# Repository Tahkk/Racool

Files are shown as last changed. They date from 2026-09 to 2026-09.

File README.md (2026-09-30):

# 🦝 Racool — Innoserv Awards Contest

<div align="center">
  Racool raccoon mascot
  
</div>

## About

This repository hosts the hardware design presented at the *Innoserv Awards Contest*, held in October 2025 in Taiwan.

**Racool** is a compact PCB that estimates how many people are present in a closed space without cameras and without identifying anyone. It combines a 60 GHz radar for presence/occupancy sensing with a CO₂ / temperature / humidity sensor, all driven by an ESP32 microcontroller with Wi‑Fi and Bluetooth LE connectivity.

## Use cases

Racool is designed for any enclosed space where occupancy and air quality matter:

- Public transport (buses, trains, metros)
- Hospital and clinic waiting rooms
- Restaurants and cafés
- Gyms and fitness clubs
- Offices, meeting rooms, classrooms

## Key features

- **Anonymous by design**: radar sensing captures no images, no sound and no personal data.
- **Air-quality awareness**: real CO₂, temperature and humidity measurements.
- **Wireless**: Wi‑Fi and BLE for data reporting.
- **Compact & simple**: single board, powered and programmed over USB‑C.

## Hardware

- **ESP32‑C3‑WROOM‑02** : Main MCU with Wi‑Fi and BLE; runs the firmware and processes sensor data 
- **BGT60TR13C** (Infineon) : 60 GHz FMCW radar sensor used for presence / occupancy detection 
- **SCD41** (Sensirion) : Photoacoustic CO₂ sensor with integrated temperature and humidity sensing 
- **MP2232HGTL** : Power management 
- **USB‑C connector** : Programming and power supply 

## How it works

```
 ┌────────────┐  SPI   ┌──────────────┐        ┌────────────────┐
 │ BGT60TR13C │───────▶│              │  Wi‑Fi │  Cloud /       │
 │ (60 GHz)   │        │  ESP32‑C3    │───────▶│  dashboard     │
 └────────────┘        │              │  BLE   │  (optional)    │
 ┌────────────┐  I²C   │              │        └────────────────┘
 │   SCD41    │───────▶│              │
 │ CO₂/T/RH   │        └──────────────┘
 └────────────┘              ▲
                        USB‑C / power
```

1. The radar captures motion and micro-motion signatures in the room.
2. The MCU processes them to estimate occupancy.
3. The SCD41 provides CO₂, temperature and humidity readings.
4. Data is sent over Wi‑Fi/BLE to a dashboard or gateway.

## Layers and 3D view

<div align="center">
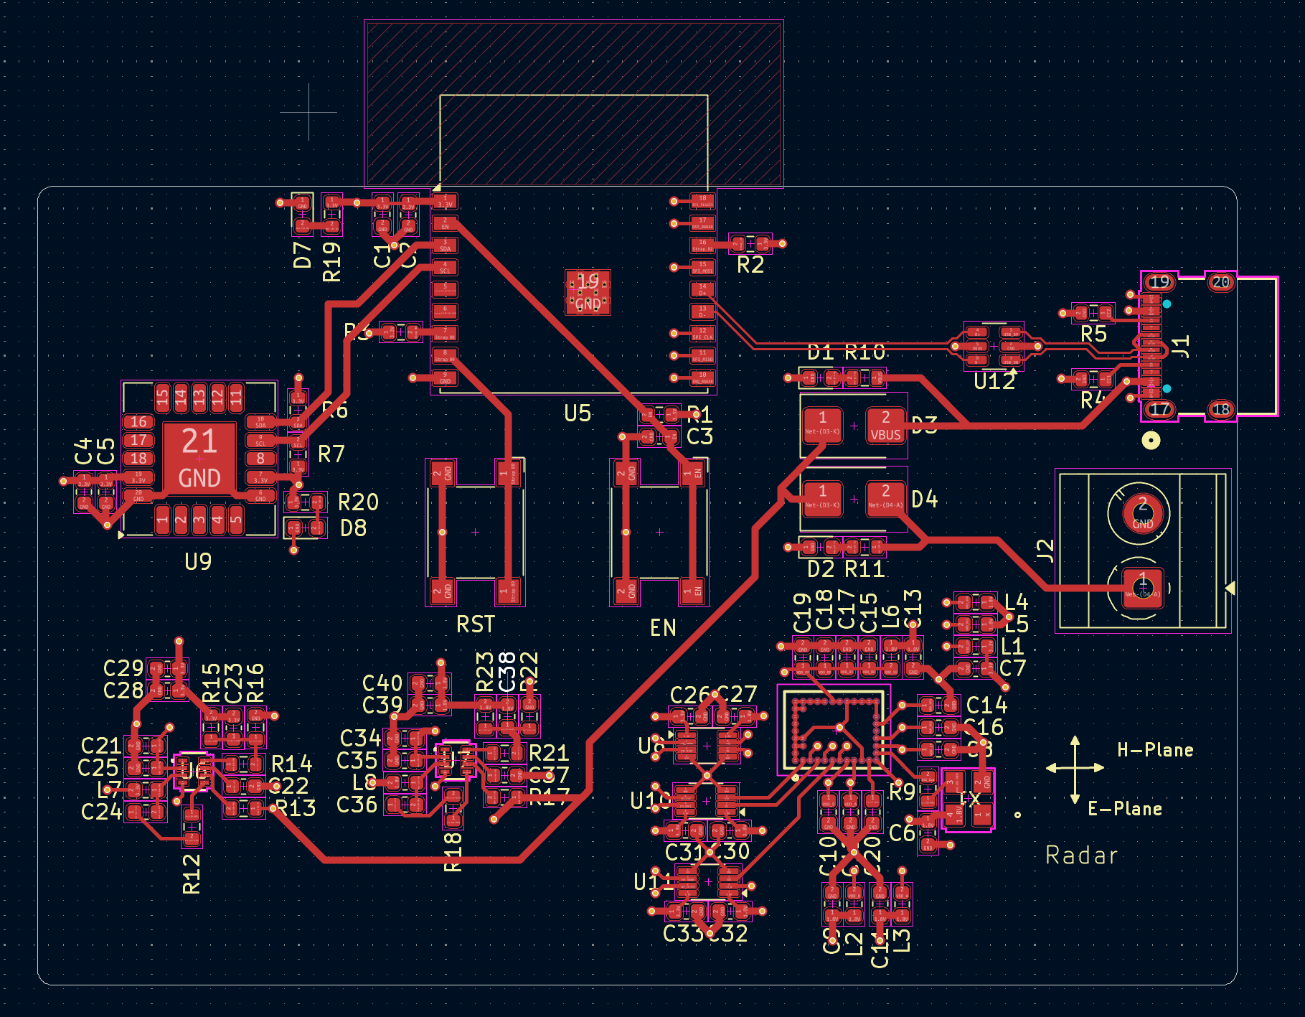
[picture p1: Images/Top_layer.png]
<br>
Top layer<br>

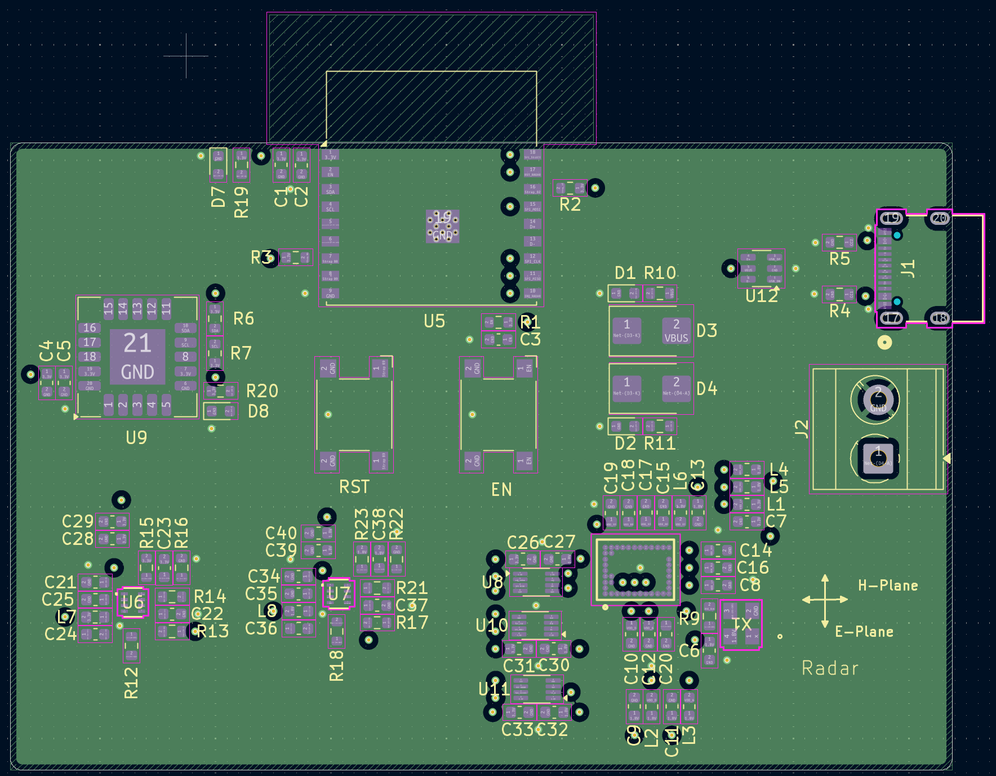
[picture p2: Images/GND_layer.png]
<br>
  Ground layer<br>
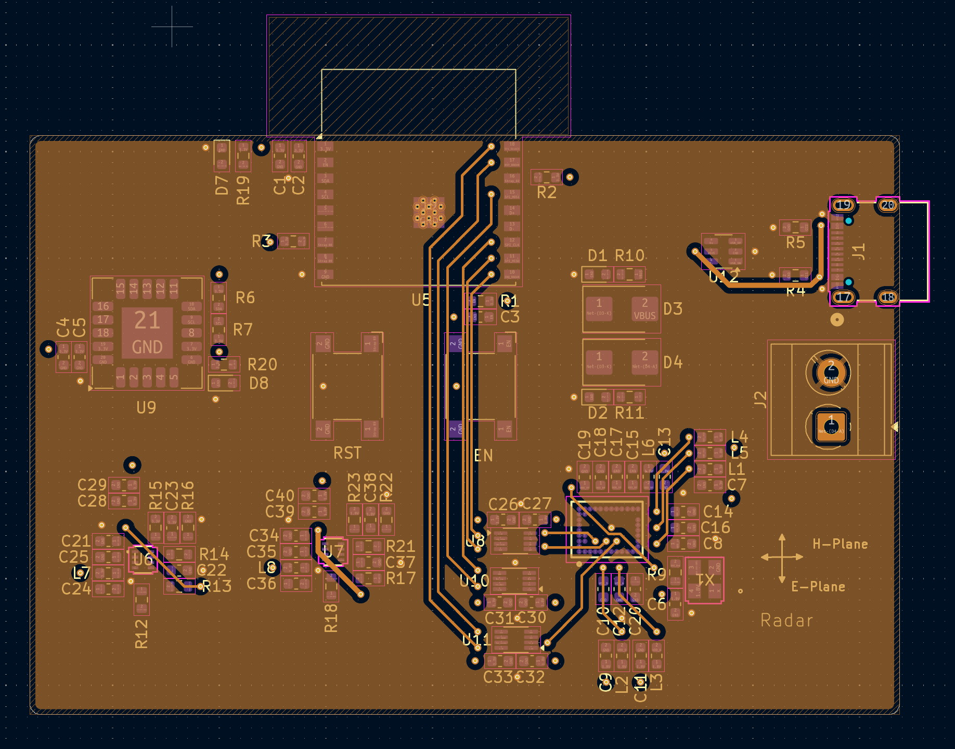
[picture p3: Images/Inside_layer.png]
<br>
  Inside layer<br>
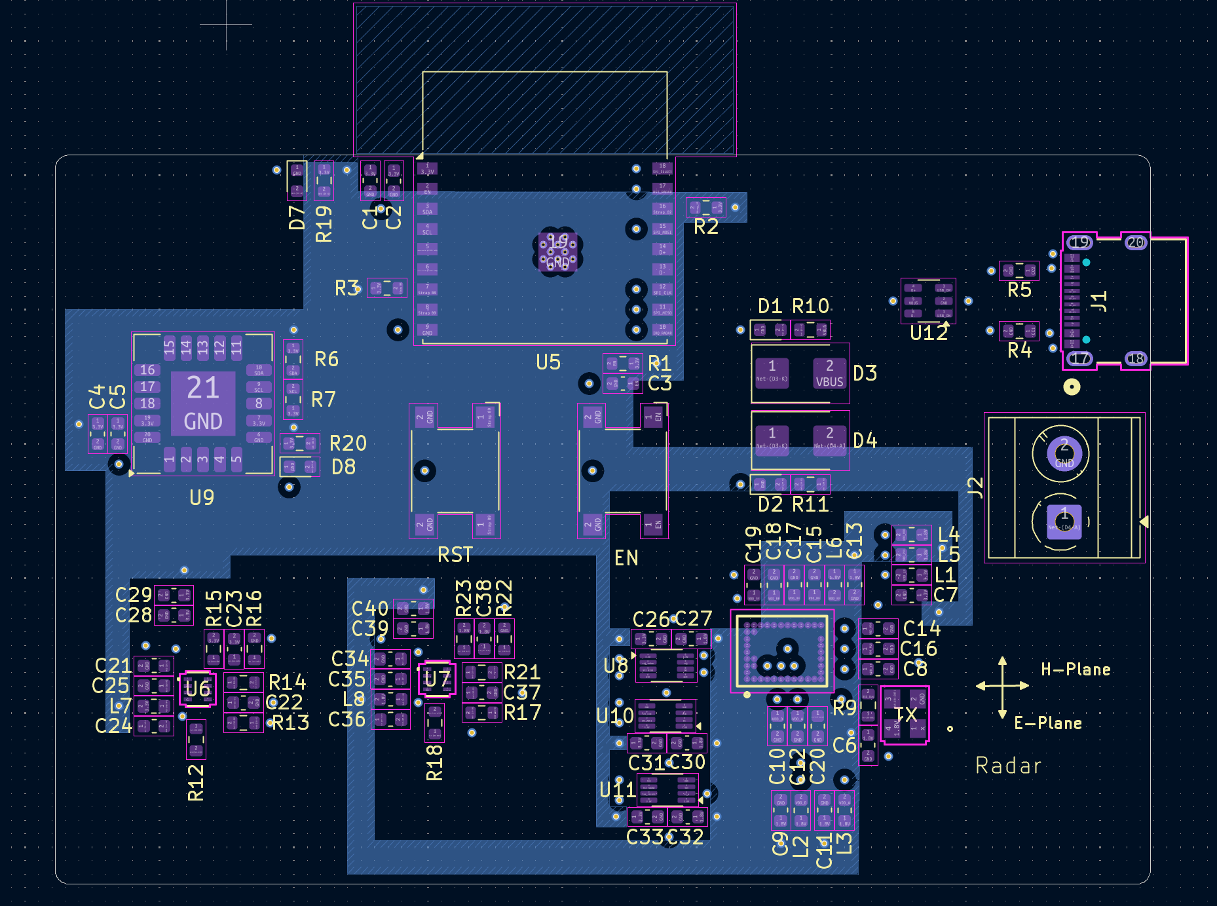
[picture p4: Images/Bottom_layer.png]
<br>
  Bottom layer<br>
</div>

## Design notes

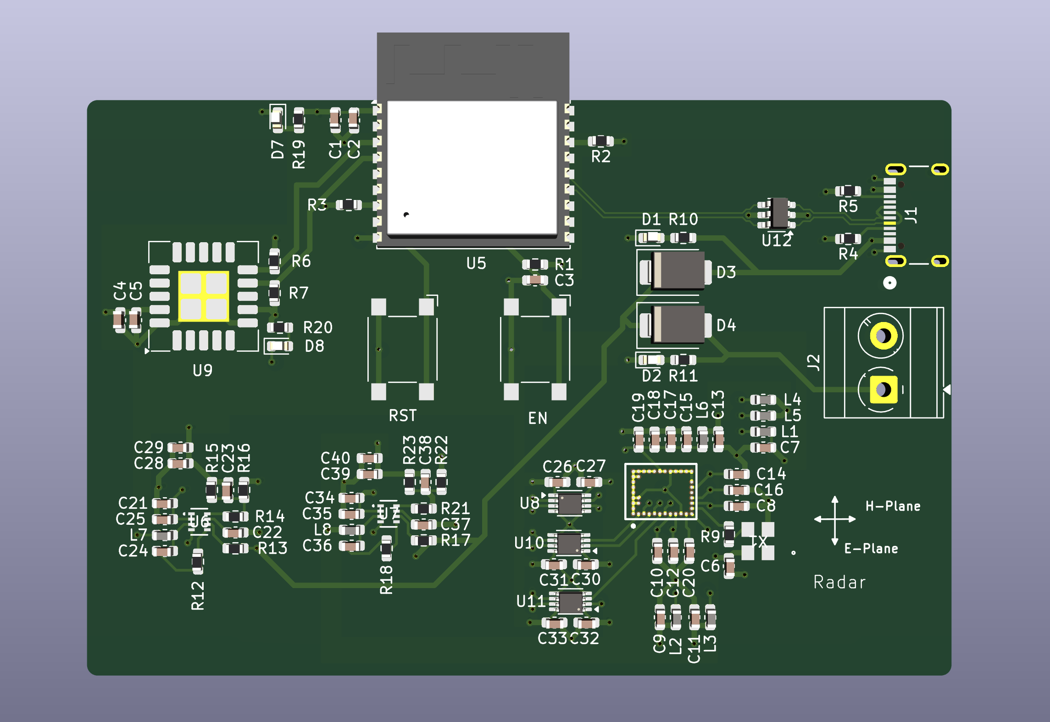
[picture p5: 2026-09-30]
Images/3D.png

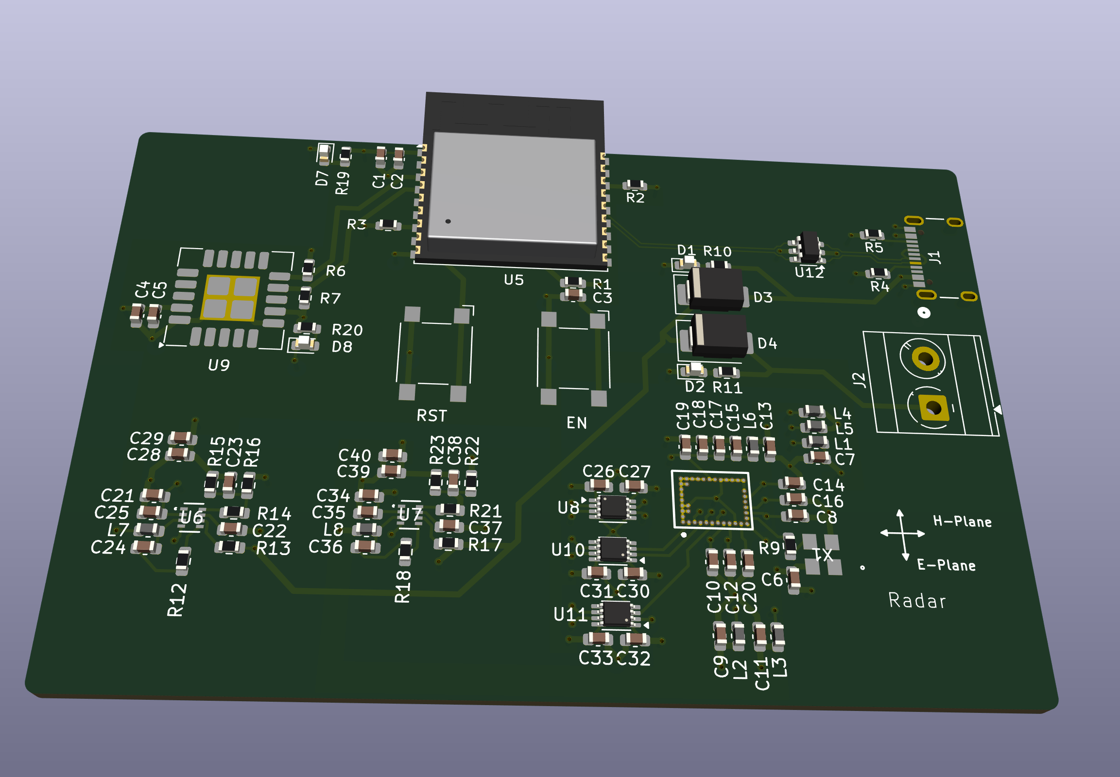
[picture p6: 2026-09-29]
Kicad_files/3D board.png

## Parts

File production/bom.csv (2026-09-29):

Designator | Footprint | Quantity | Value | LCSC Part #
C1, C12, C13, C15, C22, C37, C4, C7, C9 | 0603 | 9 | 10µF
C10, C14, C16, C17, C18, C19, C24, C3, C36, C8 | 0603 | 10 | 1µF
C11, C5 | 0603 | 2 | 100nF
C2, C25, C26, C27, C30, C31, C32, C33, C35 | 0603 | 9 | 0.1µF
C20 | 0603 | 1 | 470nF
C21, C28, C29, C34, C39, C40 | 0603 | 6 | 22µF
C23, C38 | 0603 | 2 | 10pF
C6 | 0603 | 1 | 0.01µF
D1 | 0603 | 1 | B_LED
D2, D7, D8 | 0603 | 3 | R_LED
D3, D4 | D_SMB | 2 | MBRS130LT3
EN, RST | SW_SPST_Omron_B3FS-100xP | 2 | SW_Omron_B3FS
J1 | CONN12_B-7004_GSW | 1 | GT-USB-7004
J2 | TerminalBlock_MetzConnect_Type073_RT02602HBLU_1x02_P5.08mm_Horizontal | 1 | 5V
L1, L2, L3, L4, L5, L6 | 0603 | 6 | L
L7 | 0603 | 1 | 0.47µH
L8 | 0603 | 1 | 0.68µH
R1, R2, R3 | 0603 | 3 | 10k
R10 | 0603 | 1 | 220
R11 | 0603 | 1 | 300
R12, R18 | 0603 | 2 | 20
R13, R17 | 0603 | 2 | 120k
R14, R15, R23 | 0603 | 3 | 40.2k
R16 | 0603 | 1 | 13k
R19, R20 | 0603 | 2 | 1k
R21 | 0603 | 1 | 20k
R22 | 0603 | 1 | 32.4k
R4, R5 | 0603 | 2 | 5k1
R6, R7 | 0603 | 2 | 4.7k
R9 | 0603 | 1 | 150
U$1 | BGA40N50P9X12_500X650X90-V | 1 | BGT60TR13C
U10, U11, U8 | VSSOP-8_2.3x2mm_P0.5mm | 3 | SN74LVC2T45DCUR
U12 | SOT-23-6 | 1 | USBLC6-2SC6
U5 | ESP32-C3-WROOM-02 | 1 | ESP32-C3-WROOM-02
U6, U7 | SOT583_MP2332H_MNP | 2 | MP2332HGTL-Z
U9 | Sensirion_SCD4x-1EP_10.1x10.1mm_P1.25mm_EP4.8x4.8mm | 1 | SCD41-D-R2
X1 | SON4_SIT8008_3p2x2p5_SIT | 1 | TXC CORP 7X80000600

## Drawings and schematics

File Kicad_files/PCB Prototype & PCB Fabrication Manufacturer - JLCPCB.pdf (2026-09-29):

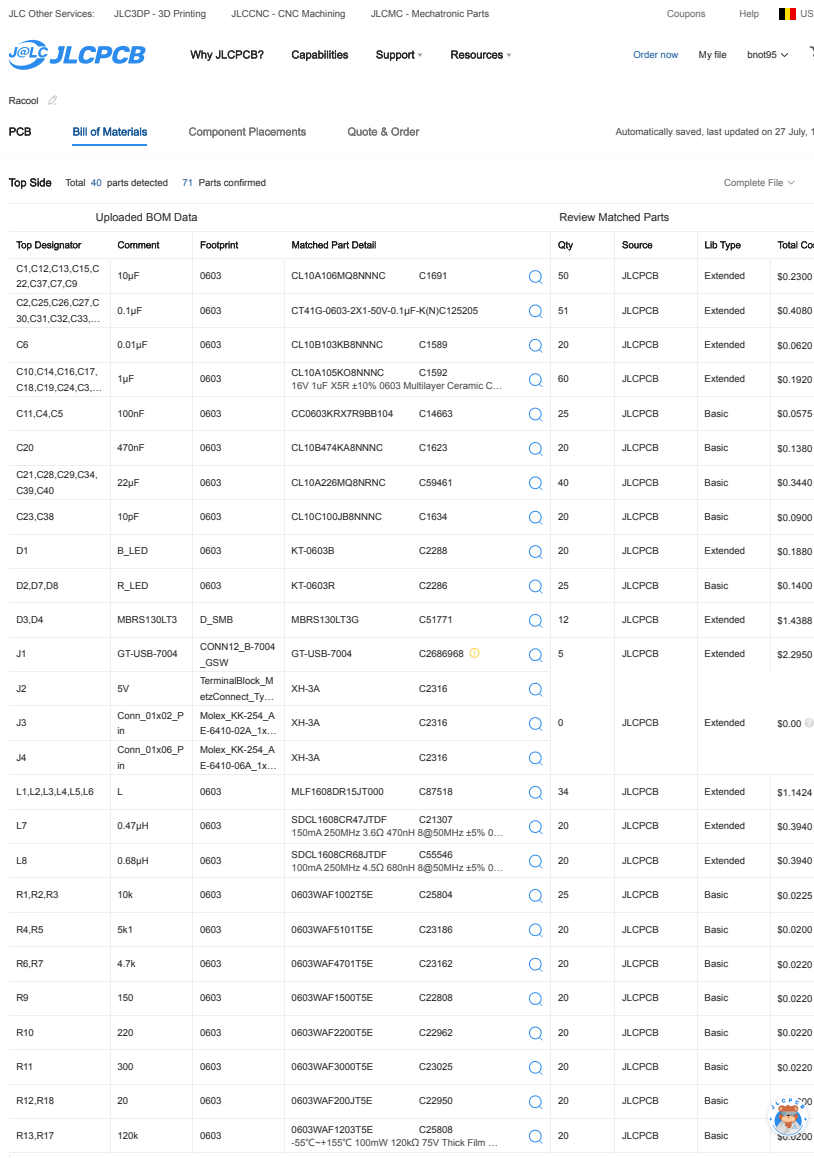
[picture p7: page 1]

Automatically saved, last updated on 27 July, 1

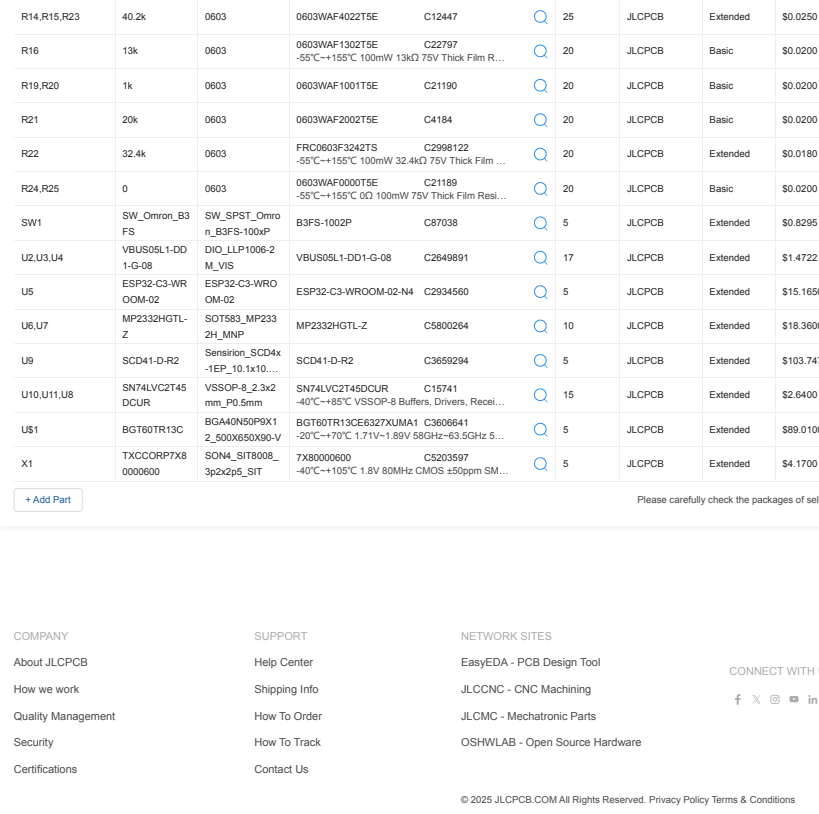
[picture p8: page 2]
COMPANY; About JLCPCB; Quality Management; Security; Certifications; SUPPORT; Help Center; Shipping Info; Contact Us; NETWORK SITES; CONNECT WITH U; + Add Part; Please carefully check the packages of sel; 0603WAF4022T5E; JLCPCB; Extended; 0603WAF1302T5E; -55℃~+155℃ 100mW 13kΩ 75V Thick Film R…; Basic; 0603WAF1001T5E; 0603WAF2002T5E; FRC0603F3242TS; -55℃~+155℃ 100mW 32.4kΩ 75V Thick Film …; 0603WAF0000T5E; SW_Omron_B3 FS; SW_SPST_Omro n_B3FS-100xP; VBUS05L1-DD 1-G-08; DIO_LLP1006-2 M_VIS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

-55℃~+155℃ 0Ω 100mW 75V Thick Film Resi…

-40℃~+85℃ VSSOP-8 Buffers, Drivers, Recei…

EasyEDA - PCB Design Tool (https://easyeda.com/)

How we work (https://jlcpcb.com/aboutUs/howWorks)

JLCCNC - CNC Machining (https://jlccnc.com/?source=jlcpcb-footer)

How To Order (https://jlcpcb.com/help/catalog/11-How-To-Order)

JLCMC - Mechatronic Parts (https://jlcmc.com/?href=jlc-footer&source=jlc)

How To Track (https://jlcpcb.com/help/article/How-to-Track-My-Order)

OSHWLAB - Open Source Hardware (https://oshwlab.com/?source=jlcpcb-footer)

© 2025 JLCPCB.COM All Rights Reserved. Privacy Policy (https://jlcpcb.com/help/article/Privacy-Policy) Terms & Conditions (https://jlcpcb.com/help/article/Terms-%26-Conditions)

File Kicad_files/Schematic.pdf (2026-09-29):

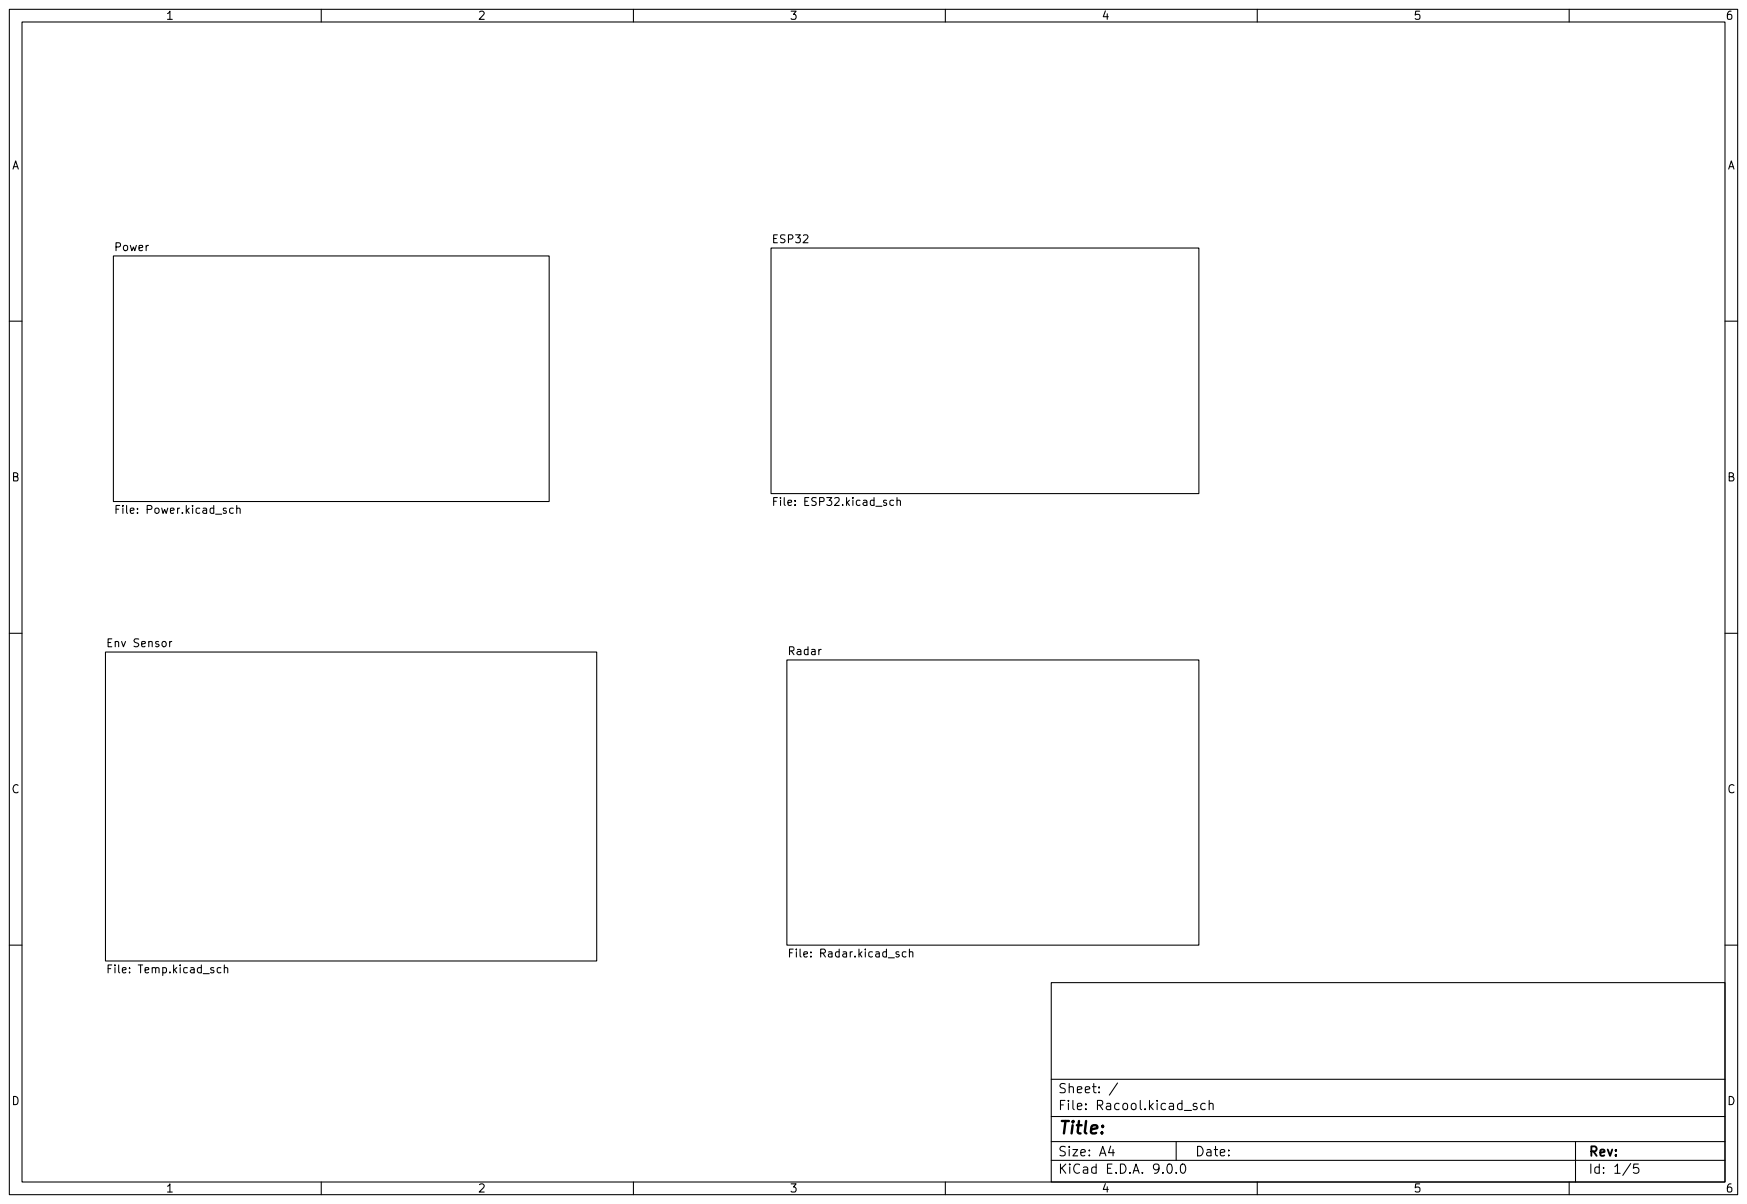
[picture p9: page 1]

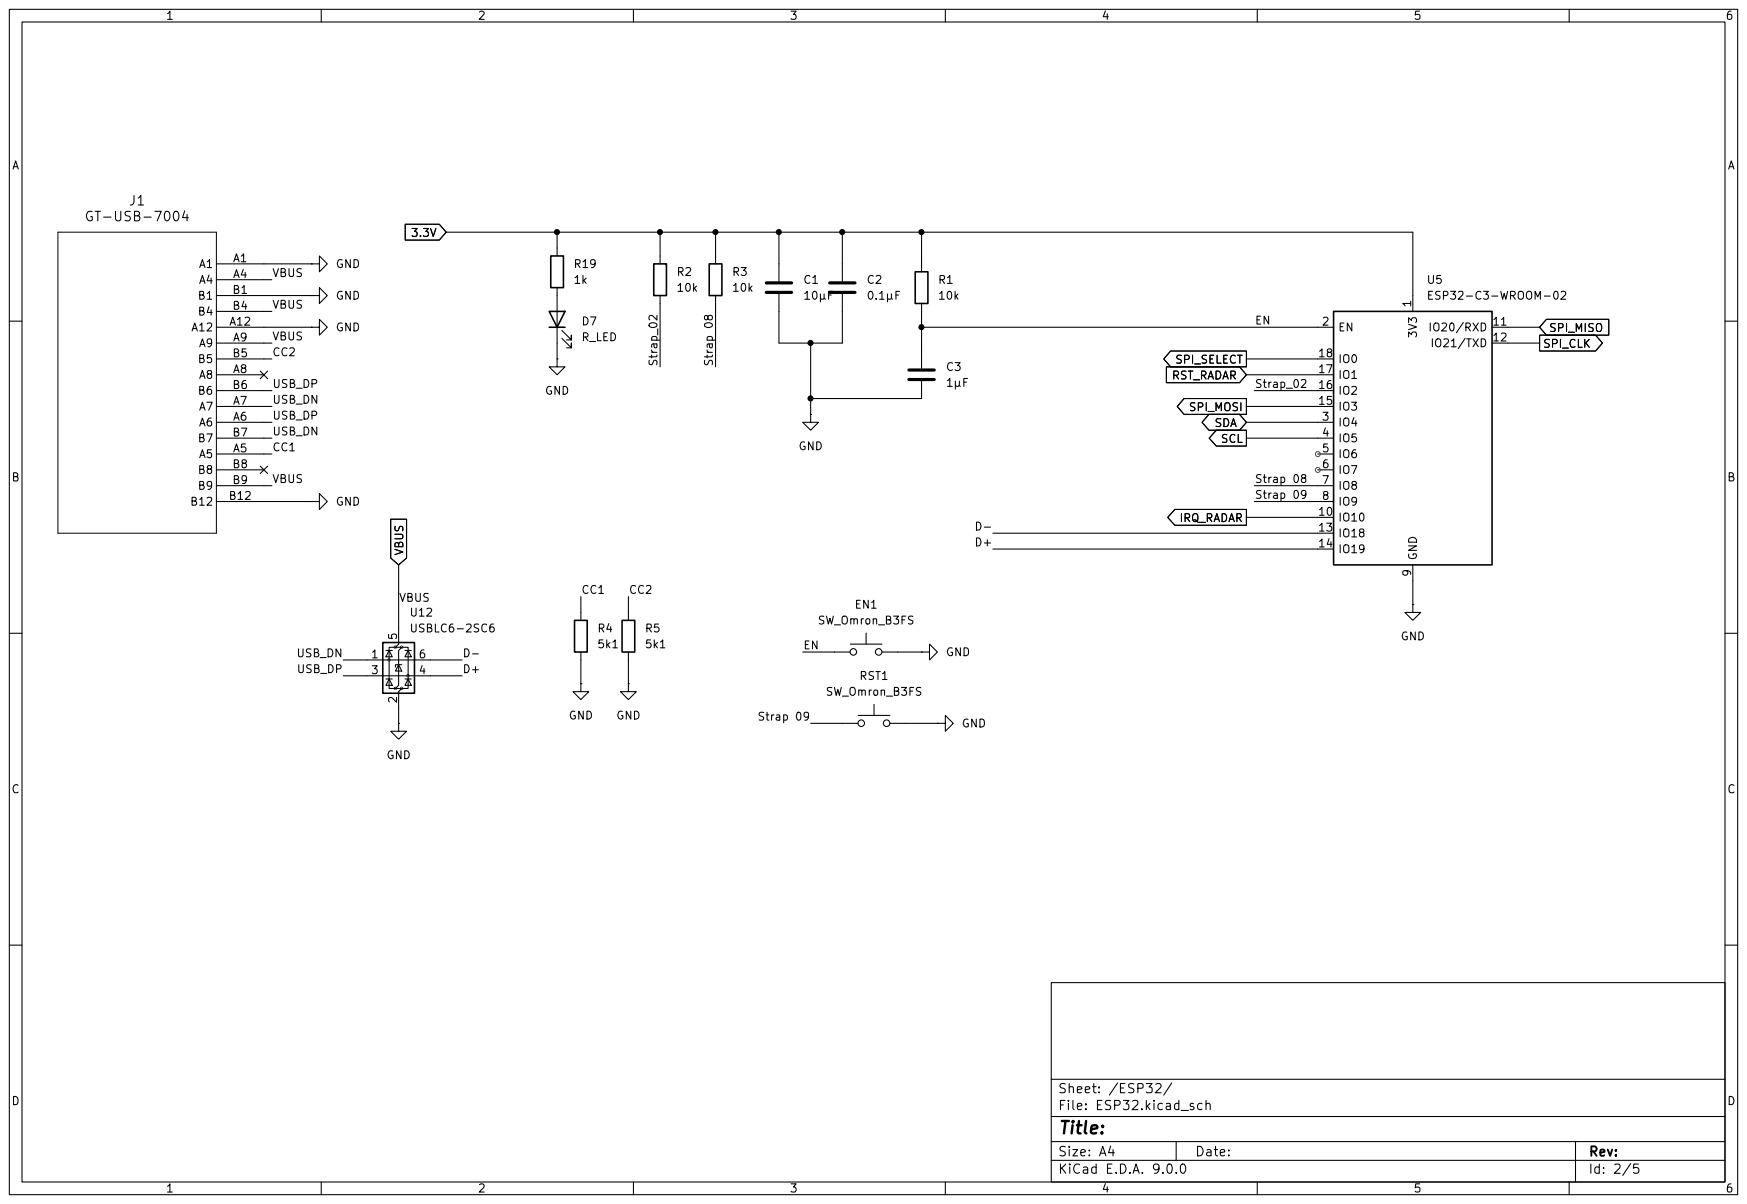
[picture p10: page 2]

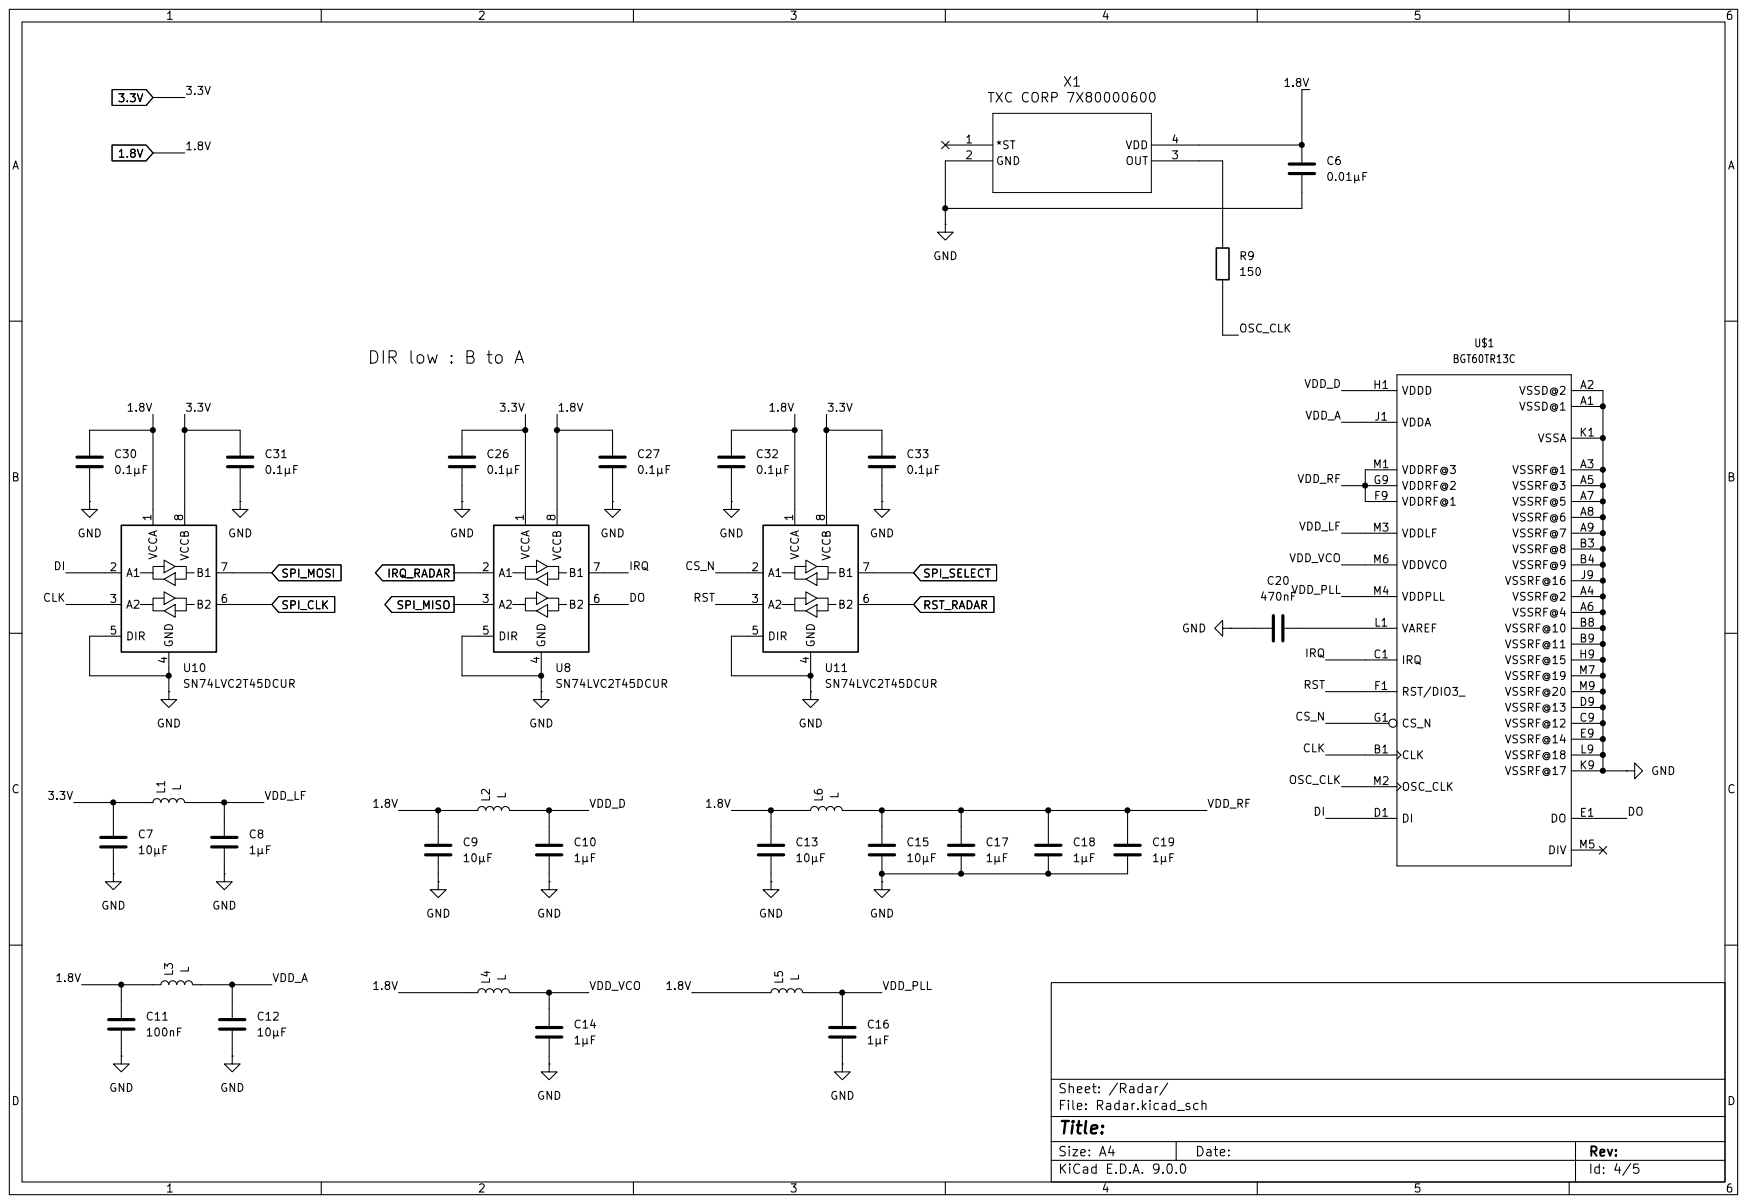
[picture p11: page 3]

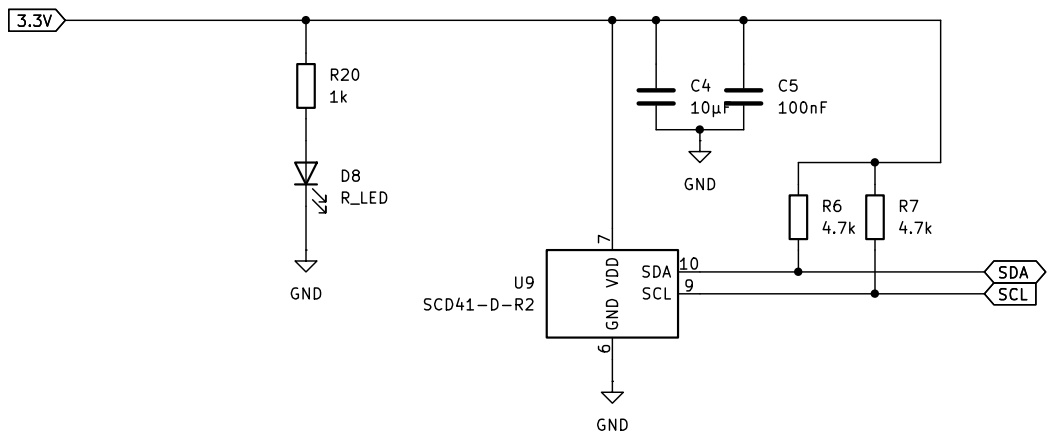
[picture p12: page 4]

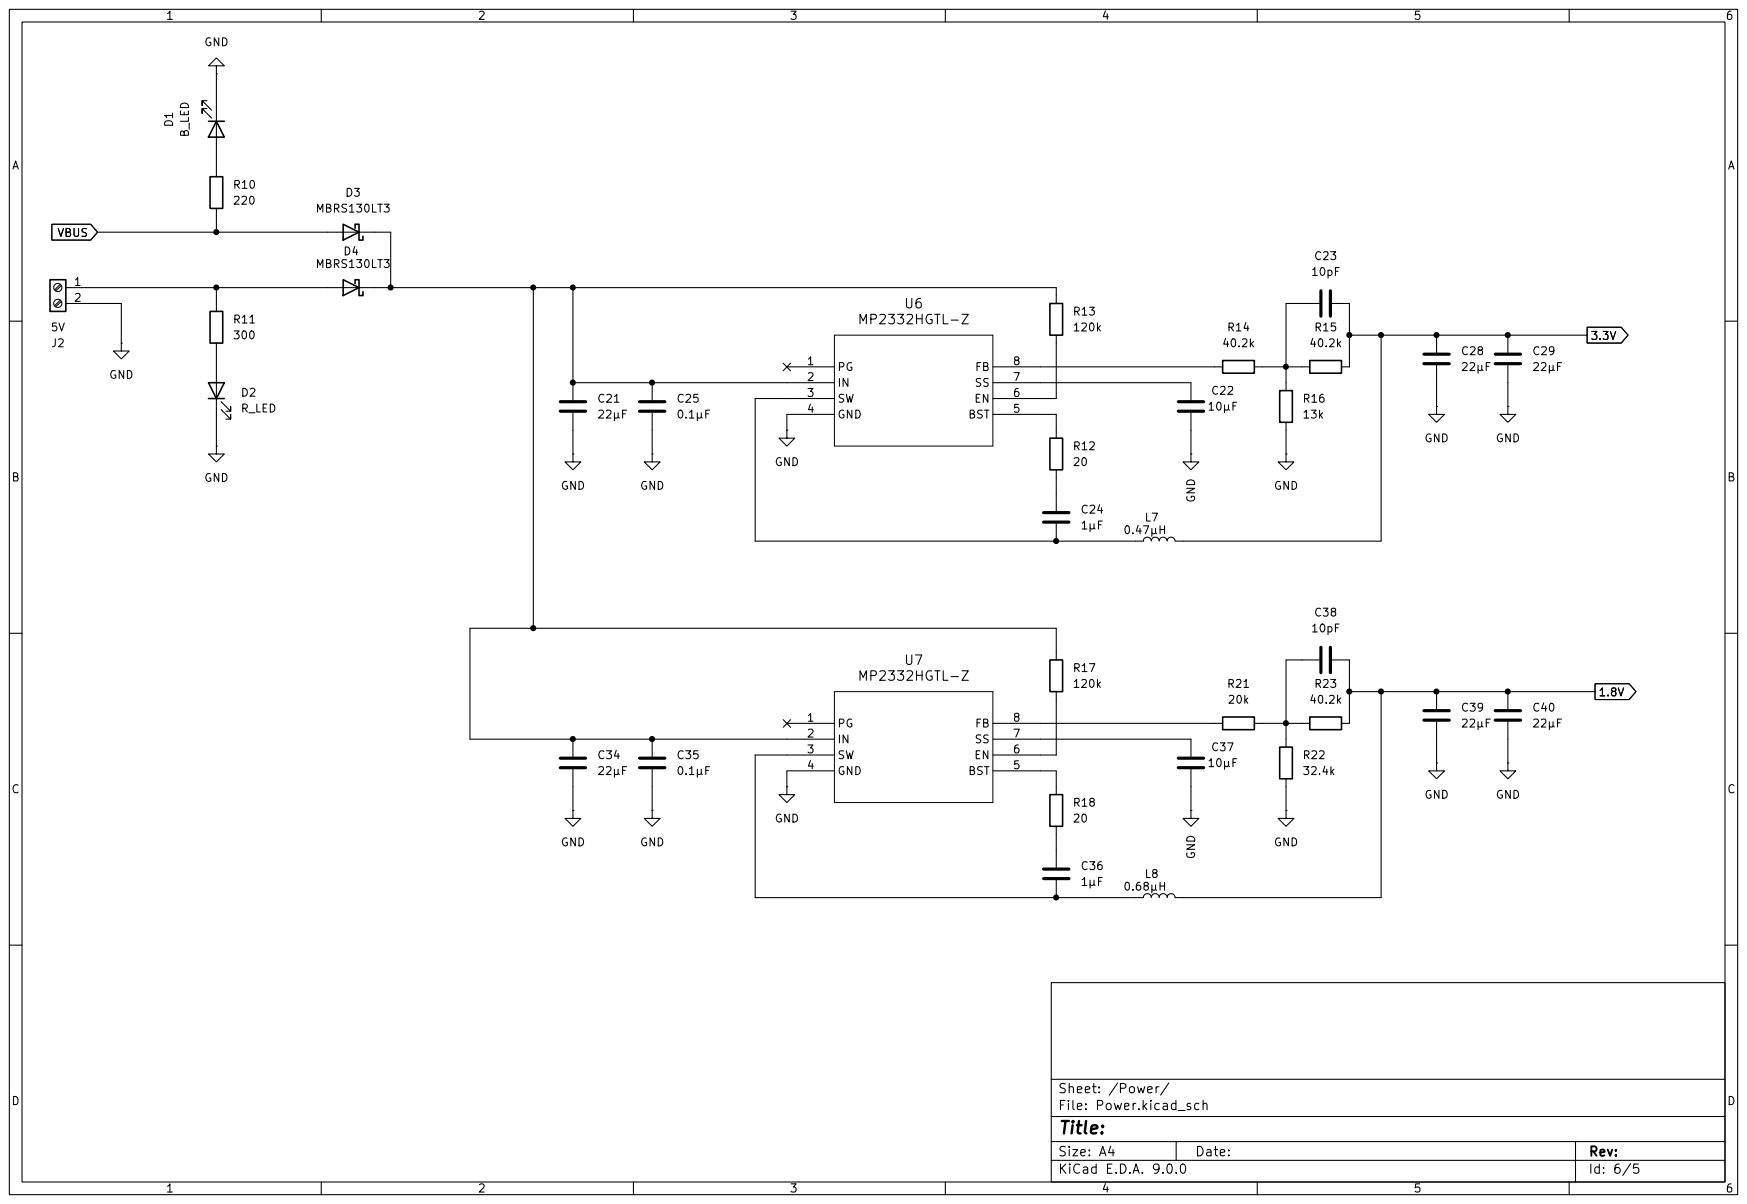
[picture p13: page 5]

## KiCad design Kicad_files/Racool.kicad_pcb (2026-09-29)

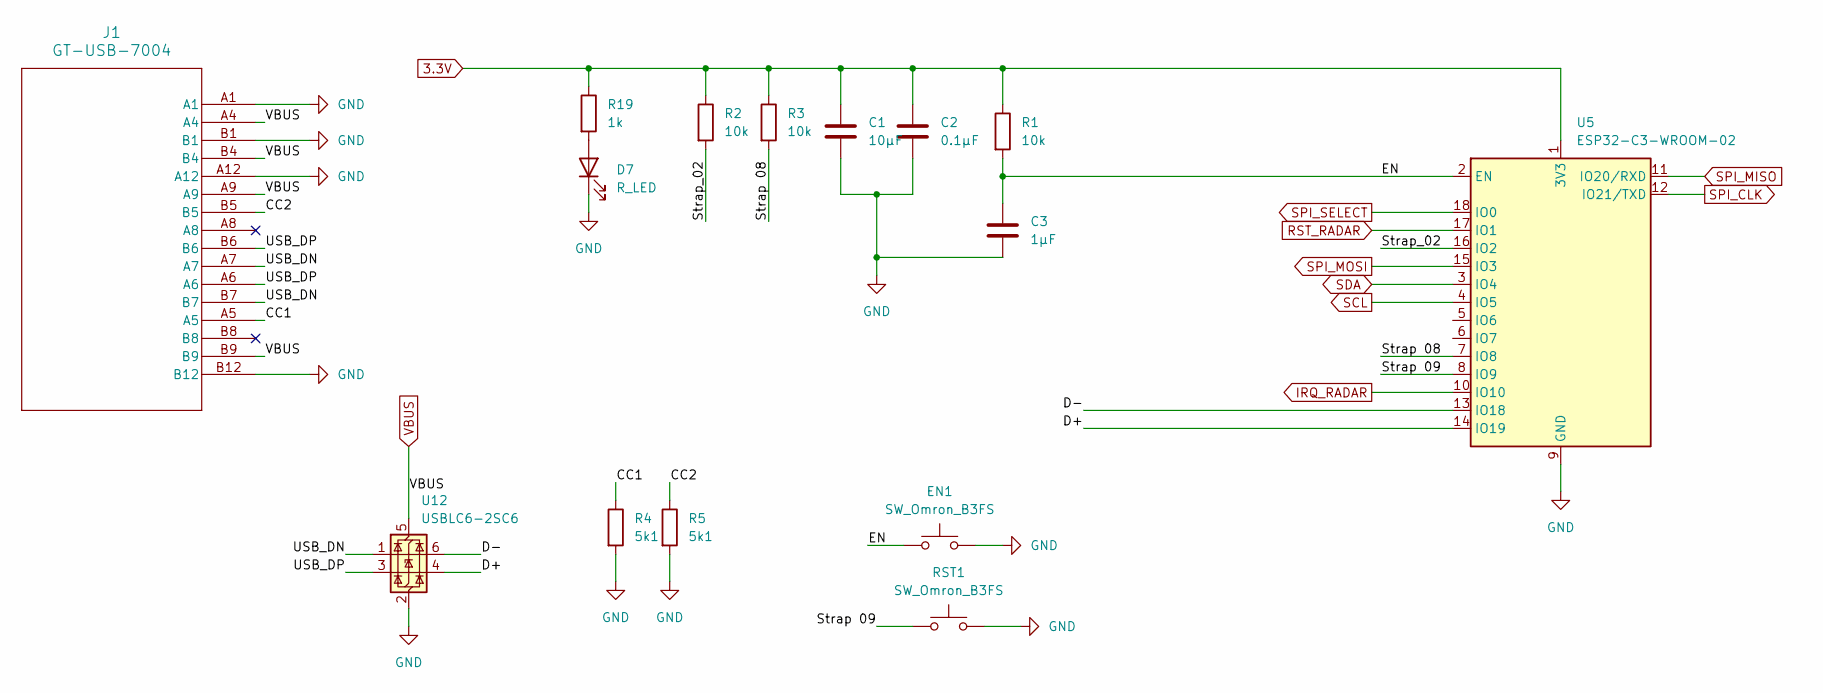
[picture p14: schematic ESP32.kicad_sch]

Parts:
C1: 10µF; C_0603_1608Metric
C2: 0.1µF; C_0603_1608Metric
C3: 1µF; C_0603_1608Metric
D7: R_LED; LED_0603_1608Metric
EN1: SW_Omron_B3FS; SW_SPST_Omron_B3FS-100xP
J1: GT-USB-7004; CONN12_B-7004_GSW
R1, R2, R3: 10k; R_0603_1608Metric
R4, R5: 5k1; R_0603_1608Metric
R19: 1k; R_0603_1608Metric
RST1: SW_Omron_B3FS; SW_SPST_Omron_B3FS-100xP
U5: ESP32-C3-WROOM-02
U12: USBLC6-2SC6; SOT-23-6

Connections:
3.3V: C1.1, C2.1, R1.1, R2.1, R3.1, R19.1, U5.1 (3V3); also elsewhere on the board
/ESP32/CC1: J1.A5, R4.1
/ESP32/CC2: J1.B5, R5.1
/ESP32/D+: U5.14 (IO19), U12.4 (I/O2)
/ESP32/D-: U5.13 (IO18), U12.6 (I/O1)
/ESP32/EN: C3.1, EN1.1, R1.2, U5.2 (EN); also elsewhere on the board
/ESP32/Strap 08: R3.2, U5.7 (IO8)
/ESP32/Strap 09: RST1.1, U5.8 (IO9); also elsewhere on the board
/ESP32/Strap_02: R2.2, U5.16 (IO2)
/ESP32/USB_DN: J1.A7, J1.B7, U12.1 (I/O1)
/ESP32/USB_DP: J1.A6, J1.B6, U12.3 (I/O2)
GND: C1.2, C2.2, C3.2, D7.1 (K), EN1.2, J1.A1, J1.A12, J1.B1, J1.B12, R4.2, R5.2, RST1.2, U5.9 (GND), U5.19 (GND), U12.2 (GND); also elsewhere on the board
IRQ_RADAR: U5.10 (IO10); also elsewhere on the board
unnamed: D7.2 (A), R19.2
RST_RADAR: U5.17 (IO1); also elsewhere on the board
SCL: U5.4 (IO5); also elsewhere on the board
SDA: U5.3 (IO4); also elsewhere on the board
SPI_CLK: U5.12 (IO21/TXD); also elsewhere on the board
SPI_MISO: U5.11 (IO20/RXD); also elsewhere on the board
SPI_MOSI: U5.15 (IO3); also elsewhere on the board
SPI_SELECT: U5.18 (IO0); also elsewhere on the board
VBUS: J1.A4, J1.A9, J1.B4, J1.B9, U12.5 (VBUS); also elsewhere on the board

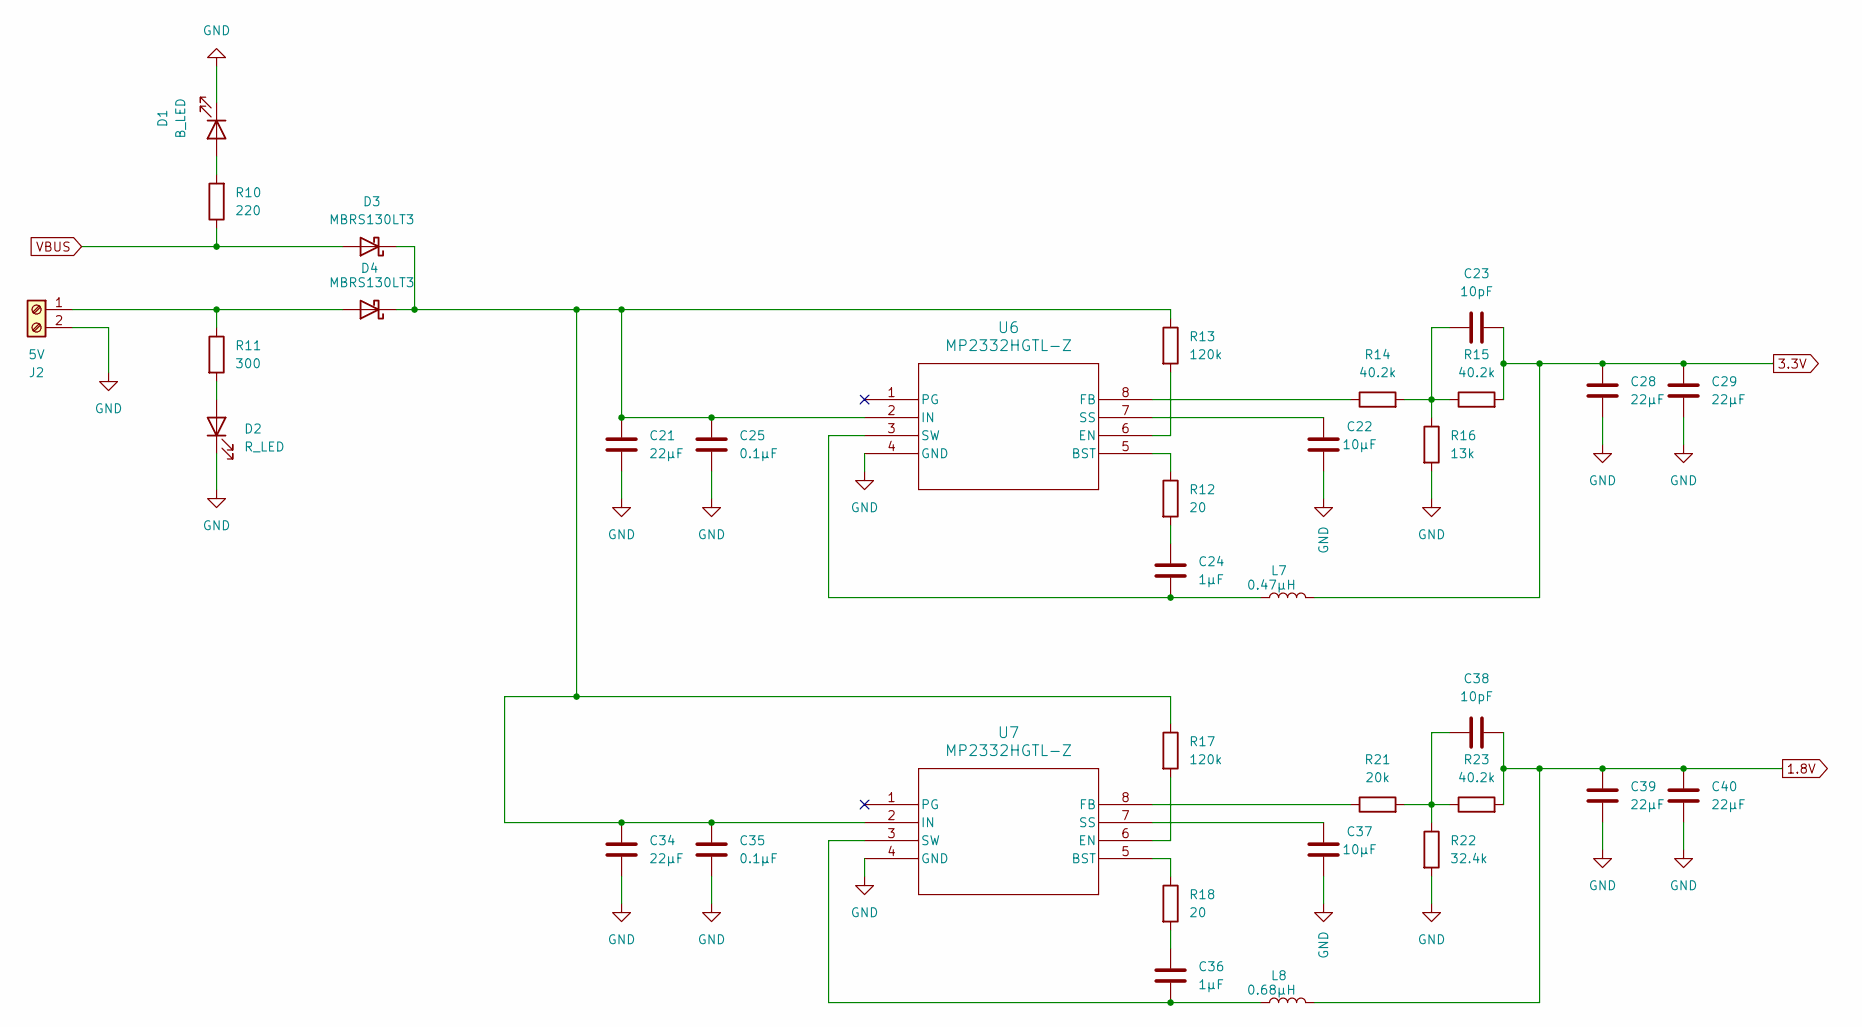
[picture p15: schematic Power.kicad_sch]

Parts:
C21, C28, C29, C34, C39, C40: 22µF; C_0603_1608Metric
C22, C37: 10µF; C_0603_1608Metric
C23, C38: 10pF; C_0603_1608Metric
C24, C36: 1µF; C_0603_1608Metric
C25, C35: 0.1µF; C_0603_1608Metric
D1: B_LED; LED_0603_1608Metric
D2: R_LED; LED_0603_1608Metric
D3, D4: MBRS130LT3; D_SMB
J2: 5V; TerminalBlock_MetzConnect_Type073_RT02602HBLU_1x02_P5.08mm_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
L7: 0.47µH; L_0603_1608Metric
L8: 0.68µH; L_0603_1608Metric
R10: 220; R_0603_1608Metric
R11: 300; R_0603_1608Metric
R12, R18: 20; R_0603_1608Metric
R13, R17: 120k; R_0603_1608Metric
R14, R15, R23: 40.2k; R_0603_1608Metric
R16: 13k; R_0603_1608Metric
R21: 20k; R_0603_1608Metric
R22: 32.4k; R_0603_1608Metric
U6, U7: MP2332HGTL-Z; SOT583_MP2332H_MNP

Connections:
1.8V: C38.2, C39.1, C40.1, L8.2, R23.2; also elsewhere on the board
3.3V: C23.2, C28.1, C29.1, L7.2, R15.2; also elsewhere on the board
GND: C21.2, C22.2, C25.2, C28.2, C29.2, C34.2, C35.2, C37.2, C39.2, C40.2, D1.1 (K), D2.1 (K), J2.2, R16.2, R22.2, U6.4 (GND), U7.4 (GND); also elsewhere on the board
unnamed: C23.1, R14.2, R15.1, R16.1
unnamed: C24.1, R12.2
unnamed: C36.1, R18.2
unnamed: C38.1, R21.2, R22.1, R23.1
unnamed: D1.2 (A), R10.2
unnamed: D2.2 (A), R11.2
unnamed: C21.1, C25.1, C34.1, C35.1, D3.1 (K), D4.1 (K), R13.1, R17.1, U6.2 (IN), U7.2 (IN)
unnamed: D4.2 (A), J2.1, R11.1
unnamed: R12.1, U6.5 (BST)
unnamed: R13.2, U6.6 (EN)
unnamed: R14.1, U6.8 (FB)
unnamed: C22.1, U6.7 (SS)
unnamed: C24.2, L7.1, U6.3 (SW)
unnamed: R18.1, U7.5 (BST)
unnamed: R17.2, U7.6 (EN)
unnamed: R21.1, U7.8 (FB)
unnamed: C37.1, U7.7 (SS)
unnamed: C36.2, L8.1, U7.3 (SW)
VBUS: D3.2 (A), R10.1; also elsewhere on the board

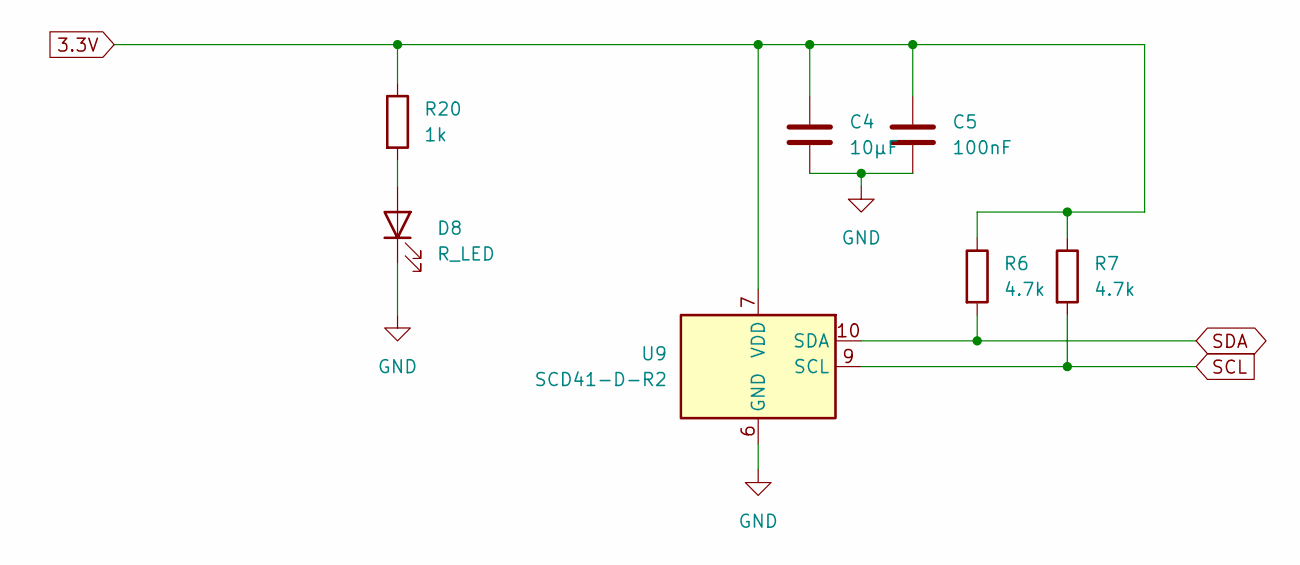
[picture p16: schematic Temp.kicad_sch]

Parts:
C4: 10µF; C_0603_1608Metric
C5: 100nF; C_0603_1608Metric
D8: R_LED; LED_0603_1608Metric
R6, R7: 4.7k; R_0603_1608Metric
R20: 1k; R_0603_1608Metric
U9: SCD41-D-R2; Sensirion_SCD4x-1EP_10.1x10.1mm_P1.25mm_EP4.8x4.8mm

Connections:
3.3V: C4.1, C5.1, R6.1, R7.1, R20.1, U9.7 (VDD), U9.19 (VDD); also elsewhere on the board
GND: C4.2, C5.2, D8.1 (K), U9.6 (GND), U9.20 (GND), U9.21 (GND); also elsewhere on the board
unnamed: D8.2 (A), R20.2
SCL: R7.2, U9.9 (SCL); also elsewhere on the board
SDA: R6.2, U9.10 (SDA); also elsewhere on the board

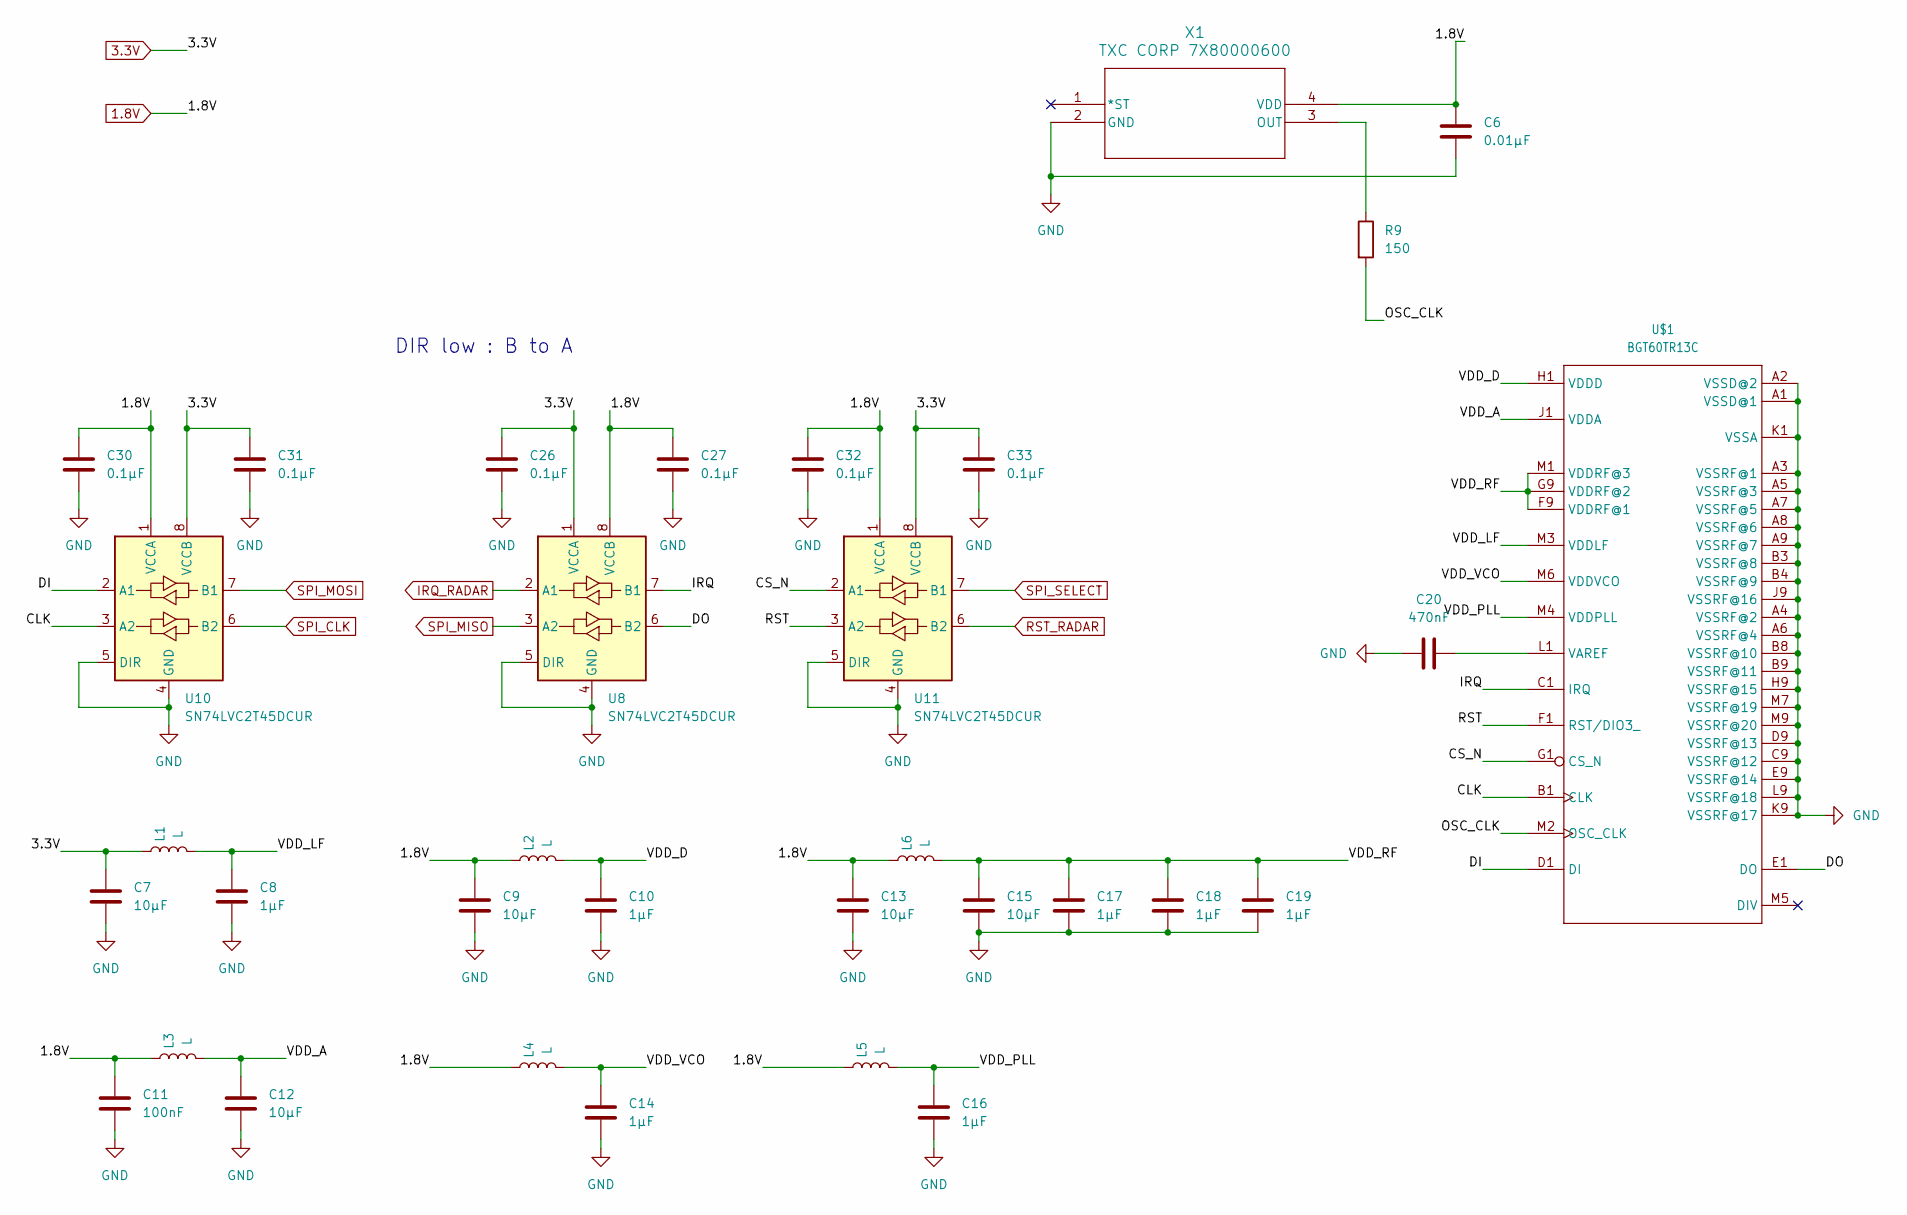
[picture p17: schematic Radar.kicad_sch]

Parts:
C6: 0.01µF; C_0603_1608Metric
C7, C9, C12, C13, C15: 10µF; C_0603_1608Metric
C8, C10, C14, C16, C17, C18, C19: 1µF; C_0603_1608Metric
C11: 100nF; C_0603_1608Metric
C20: 470nF; C_0603_1608Metric
C26, C27, C30, C31, C32, C33: 0.1µF; C_0603_1608Metric
L1, L2, L3, L4, L5, L6: L; L_0603_1608Metric
R9: 150; R_0603_1608Metric
U8, U10, U11: SN74LVC2T45DCUR; VSSOP-8_2.3x2mm_P0.5mm
U$1: BGT60TR13C; BGA40N50P9X12_500X650X90-V
X1: TXC CORP 7X80000600; SON4_SIT8008_3p2x2p5_SIT

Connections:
1.8V: C6.1, C9.1, C11.1, C13.1, C27.1, C30.1, C32.1, L2.1, L3.1, L4.1, L5.1, L6.1, U8.8 (VCCB), U10.1 (VCCA), U11.1 (VCCA), X1.4 (VDD); also elsewhere on the board
3.3V: C7.1, C26.1, C31.1, C33.1, L1.1, U8.1 (VCCA), U10.8 (VCCB), U11.8 (VCCB); also elsewhere on the board
/Radar/CLK: U10.3 (A2), U$1.B1 (CLK)
/Radar/CS_N: U11.2 (A1), U$1.G1 (CS_N)
/Radar/DI: U10.2 (A1), U$1.D1 (DI)
/Radar/DO: U8.6 (B2), U$1.E1 (DO)
/Radar/IRQ: U8.7 (B1), U$1.C1 (IRQ)
/Radar/OSC_CLK: R9.2, U$1.M2 (OSC_CLK)
/Radar/RST: U11.3 (A2), U$1.F1 (RST/DIO3_)
/Radar/VDD_A: C12.1, L3.2, U$1.J1 (VDDA)
/Radar/VDD_D: C10.1, L2.2, U$1.H1 (VDDD)
/Radar/VDD_LF: C8.1, L1.2, U$1.M3 (VDDLF)
/Radar/VDD_PLL: C16.1, L5.2, U$1.M4 (VDDPLL)
/Radar/VDD_RF: C15.1, C17.1, C18.1, C19.1, L6.2, U$1.F9 (VDDRF@1), U$1.G9 (VDDRF@2), U$1.M1 (VDDRF@3)
/Radar/VDD_VCO: C14.1, L4.2, U$1.M6 (VDDVCO)
GND: C6.2, C7.2, C8.2, C9.2, C10.2, C11.2, C12.2, C13.2, C14.2, C15.2, C16.2, C17.2, C18.2, C19.2, C20.2, C26.2, C27.2, C30.2, C31.2, C32.2, C33.2, U8.4 (GND), U8.5 (DIR), U10.4 (GND), U10.5 (DIR), U11.4 (GND), U11.5 (DIR), U$1.A1 (VSSD@1), U$1.A2 (VSSD@2), U$1.A3 (VSSRF@1), U$1.A4 (VSSRF@2), U$1.A5 (VSSRF@3), U$1.A6 (VSSRF@4), U$1.A7 (VSSRF@5), U$1.A8 (VSSRF@6), U$1.A9 (VSSRF@7), U$1.B3 (VSSRF@8), U$1.B4 (VSSRF@9), U$1.B8 (VSSRF@10), U$1.B9 (VSSRF@11), U$1.C9 (VSSRF@12), U$1.D9 (VSSRF@13), U$1.E9 (VSSRF@14), U$1.H9 (VSSRF@15), U$1.J9 (VSSRF@16), U$1.K1 (VSSA), U$1.K9 (VSSRF@17), U$1.L9 (VSSRF@18), U$1.M7 (VSSRF@19), U$1.M9 (VSSRF@20), X1.2 (GND); also elsewhere on the board
IRQ_RADAR: U8.2 (A1); also elsewhere on the board
unnamed: C20.1, U$1.L1 (VAREF)
unnamed: R9.1, X1.3 (OUT)
RST_RADAR: U11.6 (B2); also elsewhere on the board
SPI_CLK: U10.6 (B2); also elsewhere on the board
SPI_MISO: U8.3 (A2); also elsewhere on the board
SPI_MOSI: U10.7 (B1); also elsewhere on the board
SPI_SELECT: U11.7 (B1); also elsewhere on the board

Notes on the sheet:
DIR low : B to A

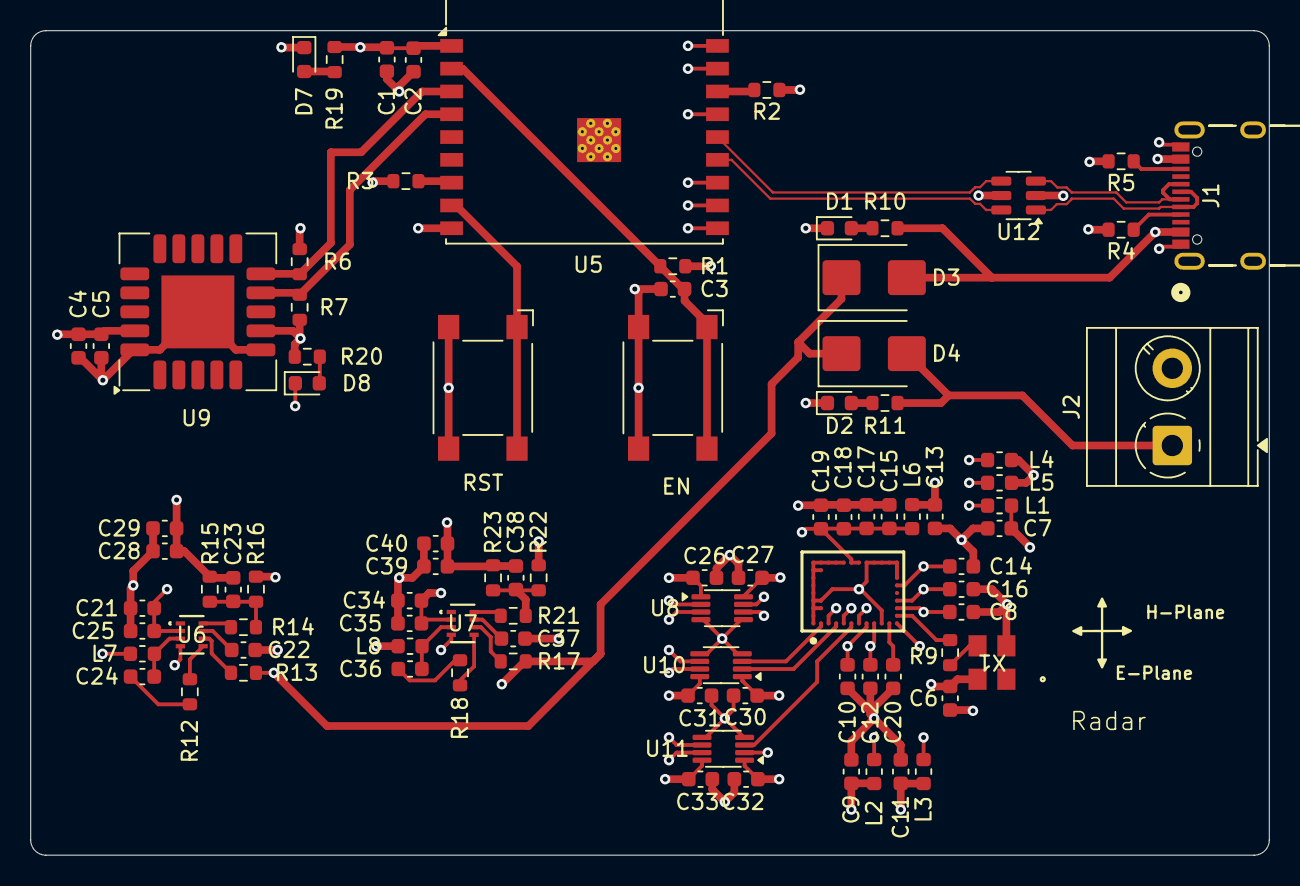
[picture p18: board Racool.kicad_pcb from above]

Board: 4 copper layers, 81.5 x 54.2 mm, 90 parts (0 on the bottom side), 57 nets.

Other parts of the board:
EN: SW_Omron_B3FS; SW_SPST_Omron_B3FS-100xP
RST: SW_Omron_B3FS; SW_SPST_Omron_B3FS-100xP

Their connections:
/ESP32/EN: EN.1; also elsewhere on the board
/ESP32/Strap 09: RST.1; also elsewhere on the board
GND: EN.2, RST.2; also elsewhere on the board
